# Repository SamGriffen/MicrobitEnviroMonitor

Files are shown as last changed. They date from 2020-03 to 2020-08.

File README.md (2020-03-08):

# MicrobitEnviroMonitor
ESP based webserver for displaying data from weather:bit. This project will allow for the sparkfun weather:bit to send data to an ESP32, which will then display the data on a local webpage. The ESP32 must have a network to connect to, it does not create it's own local access point.
 
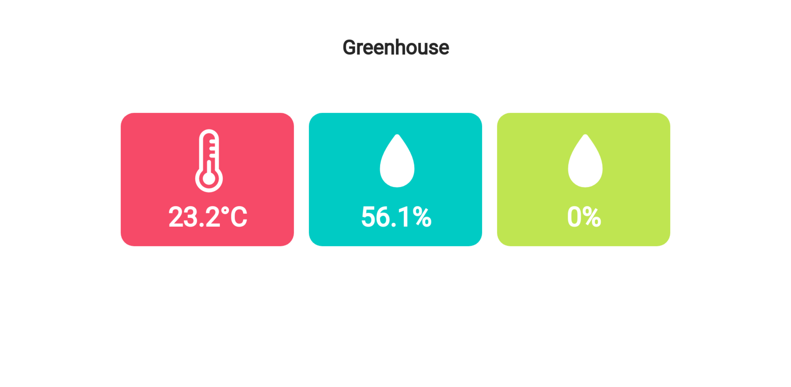
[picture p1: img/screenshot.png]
web interface
 
 
# MicroBit Code
MicroBit code can be downloaded here: https://makecode.microbit.org/_66RTrKJwsf48
The hex file can be found in the `microbit` folder of the repository.
 
 # Setup
 After cloning the repository, the project can be opened in PlatformIO. Web data is loaded into the SPIFFs storage on the ESP32, and the platformio config files are setup to allow for this. To install out of the box you must do the following:
 
 - Edit `ssid` and `password` at the top of the file to contain your WiFi network credentials.
 - Plug in ESP32.
 - From terminal, run `pio run --target uploadfs` in the root directory of the project. This will upload all web files to the ESP.
 - The project can then be uploaded as per usual.
 - Once running, the IP address of the ESP should be logged to the serial monitor (If DEBUG is defined). Navigate to this in a web browser, and the interface should appear.
 
 # Wiring Notes
 The following connections need to be made:
 weather:bit RX --> ESP32 GPIO17
 weather:bit TX --> ESP32 GPIO16
 weather:bit GND --> ESP32 GND

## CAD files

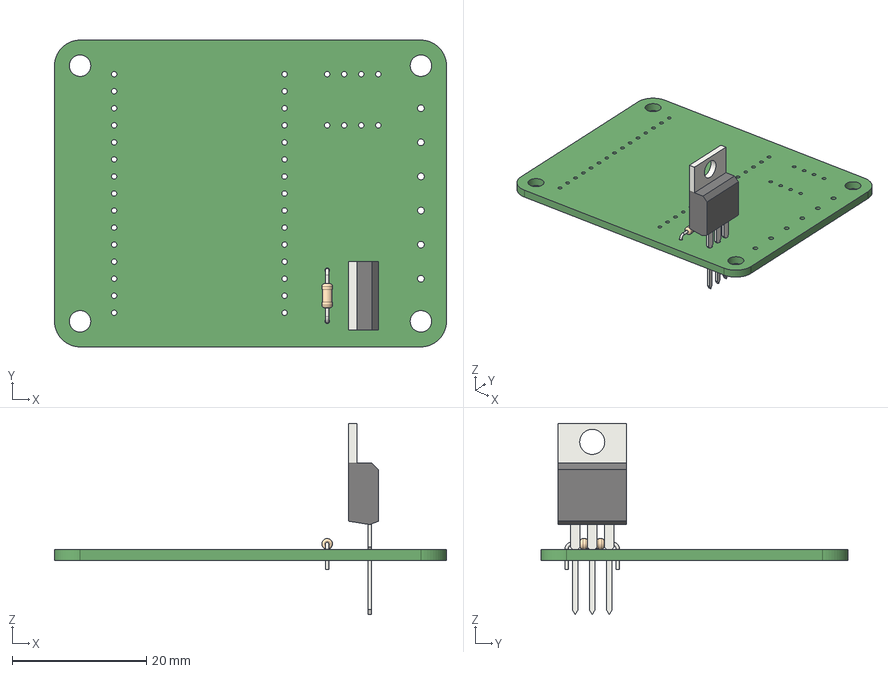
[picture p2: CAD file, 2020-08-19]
KiCAD/microbit-enviromonitor-board/microbit-enviromonitor-board.step
58.4 x 45.7 x 28.5 mm

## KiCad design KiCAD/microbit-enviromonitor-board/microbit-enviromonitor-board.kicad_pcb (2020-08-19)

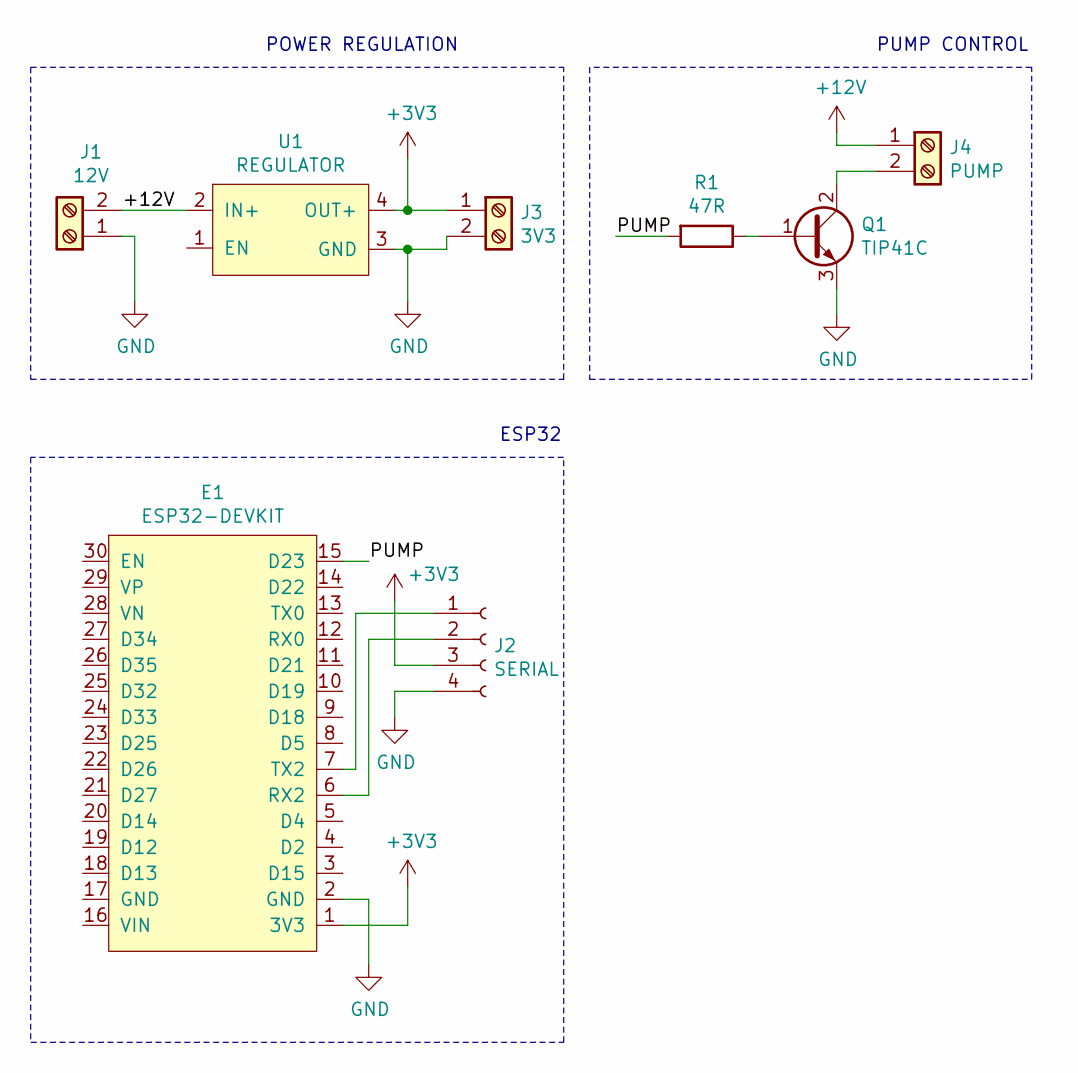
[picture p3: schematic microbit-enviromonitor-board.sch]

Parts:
E1: ESP32-DEVKIT; ESP31-DEVKIT
J1: 12V; screw_terminal
J2: SERIAL; 4x1
J3: 3V3; screw_terminal
J4: PUMP; screw_terminal
Q1: TIP41C; TO-220-3_Horizontal_TabDown
R1: 47R; R_Axial_DIN0204_L3.6mm_D1.6mm_P7.62mm_Horizontal
U1: REGULATOR; buck_converter

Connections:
+3V3: E1.1 (3V3), J2.3, J3.1, U1.4 (OUT+)
+12V: J1.2, J4.1, U1.2 (IN+)
/PUMP: E1.15 (D23), R1.2
GND: E1.2 (GND), J1.1, J2.4, J3.2, Q1.3 (E), U1.3 (GND)
unnamed: E1.6 (RX2), J2.2
unnamed: E1.7 (TX2), J2.1
unnamed: J4.2, Q1.2 (C)
unnamed: Q1.1 (B), R1.1

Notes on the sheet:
POWER REGULATION
PUMP CONTROL
ESP32

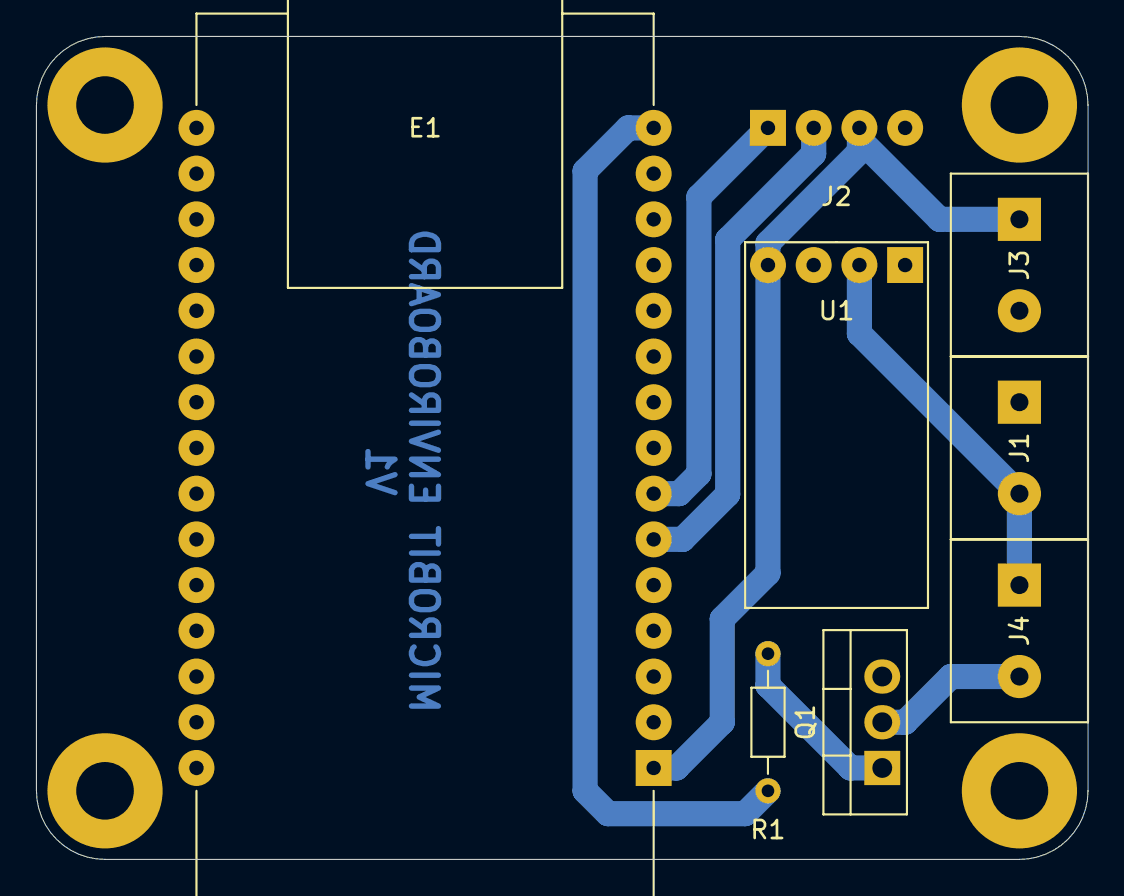
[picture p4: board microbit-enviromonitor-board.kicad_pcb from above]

Board: 2 copper layers, 58.4 x 45.7 mm, 8 parts (0 on the bottom side), 8 nets.

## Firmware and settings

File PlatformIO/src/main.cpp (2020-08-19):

/**
 * Code for Microbit based Environmental Monitoring station.
 * 
 * Data is received via serial, in the following format:
 * [temperature, in... centidegrees? Divide value by 100 to get degrees celsius], [humidity, divide by 1024 to get % relative humidity], [soil moisture. 0-1023, 0 being dry, 1023 being wet], [wind speed in m/s], [wind direction string], [mm of rain]
 * 
 * TODO: Make SOIL_DRY adjustable without reprogramming. This poses a security risk, so will need to be secure and able to detect misuse (Such as leaving the pump on indefinitely)
 * TODO: Handle rain gauge
 */

#include <Arduino.h>
#include <WiFi.h>
#include <ESPAsyncWebServer.h>
#include <SPIFFS.h>

#define DEBUG

// Define the point at which the soil is defined as "dry". Any value below this will activate the pump
// TODO: Make this editable via the frontend interface
#define SOIL_DRY 600

// Define pump output, and pump state flag
#define PUMP_PIN 23
bool pump_on = false; // Pump state. True = on, false = off


#define PUMP_BUTTON 18 // For attaching a pump activate button. When pressed, the pump will activate for roughly a minute.


// Network credentials

// const char* ssid = "BV9800";
// const char* password = "testpassword";

// Struct for storing current reading data
struct Data{
  double temp; // Temperature in degrees celsius
  double humidity; // Relative humidity [%]
  int soil_moist; // Soil moisture. A reading between 0 and 1024. This needs to be manually read and tuned, it doesn't really mean a whole lot
  double wind_speed; // Wind speed in meters per second
  char wind_dir[3];  // Wind direction, string containing "N", "NE", "E", "SE", "S" "SW", "W", or "NW"
  double rain;  // mm of rainfall since last reading was sent
} data;

#ifdef DEBUG
// If there is debugging enabled, declare a function for printing the data read
void printData(Data dat){
  Serial.print("Temperature: ");Serial.println(dat.temp);
  Serial.print("Humidity: ");Serial.println(dat.humidity);
  Serial.print("Soil Moisture: ");Serial.println(dat.soil_moist);
  Serial.print("Wind Speed ");Serial.println(dat.wind_speed);
  Serial.print("Wind Direction: ");Serial.println(dat.wind_dir);
  Serial.print("Last Hour of Rain: ");Serial.println();
}
#endif

char buffer[32]; // Buffer for storing incoming serial data for processing

bool reading = false; // Represents whether serial data is currently being read
int buf_cur = 0; // Current position in buffer

// Methods for handling Serial data
void incoming();
void processBuffer();

/* NETWORK SETUP */

// Create AsyncWebServer object on port 80
AsyncWebServer server(80);

// Method for processing HTML templates
String processor(const String& var);

// Configure the pump button interrupt routine
unsigned long press_length = 60000; // When the button is pressed, leave the pump on for a minute
unsigned long press_time = 0;
bool pressed = false;

void IRAM_ATTR ISR(){
  pump_on = true;
  press_time = millis();
  pressed = true;
}

void setup() {
  pinMode(PUMP_BUTTON, INPUT_PULLUP); // Set the pump input button as a pulup input

  attachInterrupt(PUMP_BUTTON, ISR, FALLING);

  Serial.begin(9600);

  #ifdef DEBUG
  while(!Serial){}
  #endif

  Serial2.begin(9600); // Initialise Serial communication with the microbit

  // Initialise the pump
  pinMode(PUMP_PIN, OUTPUT);
  digitalWrite(PUMP_PIN, pump_on);

  if(!SPIFFS.begin(true)){ // Attempt to initialise SPIFFS
    #ifdef DEBUG
    Serial.println("SPIFFS could not be initialised.");
    #endif
    return;
  }

  // Connect to Wi-Fi
  WiFi.begin(ssid, password);
  while (WiFi.status() != WL_CONNECTED) {
    delay(1000);
    #ifdef DEBUG
    Serial.println("Connecting to WiFi..");
    #endif
  }

  // Print ESP32 Local IP Address
  Serial.println(WiFi.localIP());

  // Configure all the routes on the HTTP server

  // Serve basic webpage
  server.on("/", HTTP_GET, [](AsyncWebServerRequest *request){
    request->send(SPIFFS, "/index.html", String(), false, processor);
  });

  // Serve request for page data
  server.on("/data", HTTP_GET, [](AsyncWebServerRequest *request){
    char buf[256];
    memset(buf, 0, 256);

    // Convert all floats to strings
    char temp[6];
    dtostrf(data.temp, 4,1, temp);

    char humidity[6];
    dtostrf(data.humidity, 3,1, humidity);

    char wind[5];
    dtostrf(data.wind_speed, 4, 2, wind);

    sprintf(buf, "{\"temp\":%s, \"humidity\":%s, \"soil_moist\":%d, \"wind_speed\":%s, \"wind_dir\":\"%s\", \"pump_on\":%d}", temp, humidity, data.soil_moist, wind, data.wind_dir, pump_on);

    request->send(200, "application/json", buf);
  });

  // Serve stylesheet
  server.on("/styles.css", HTTP_GET, [](AsyncWebServerRequest *request){
    request->send(SPIFFS, "/styles.css","text/css");
  });

  // Serve SVG images
  server.on("/drop.svg", HTTP_GET, [](AsyncWebServerRequest *request){
    request->send(SPIFFS, "/drop.svg","image/svg+xml");
  });

  server.on("/temp.svg", HTTP_GET, [](AsyncWebServerRequest *request){
    request->send(SPIFFS, "/temp.svg","image/svg+xml");
  });
  
  server.on("/plant.svg", HTTP_GET, [](AsyncWebServerRequest *request){
    request->send(SPIFFS, "/plant.svg","image/svg+xml");
  });

  server.on("/plant_water.svg", HTTP_GET, [](AsyncWebServerRequest *request){
    request->send(SPIFFS, "/plant_water.svg","image/svg+xml");
  });

  server.on("/wind.svg", HTTP_GET, [](AsyncWebServerRequest *request){
    request->send(SPIFFS,"/wind.svg"
    ,"image/svg+xml");
  });

  // Serve JavaScript file
  server.on("/main.js", HTTP_GET, [](AsyncWebServerRequest *request){
    request->send(SPIFFS, "/main.js","text/javascript");
  });

  server.on("/set_pump", HTTP_POST, [](AsyncWebServerRequest *request){
    pump_on = request->getParam("pump_on", true)->value() == "true";
    Serial.print("Pump: ");Serial.println(pump_on);
    request->send(200, "text/plain", "OK");
  });

  // Admin interface - Crudely password protected by ADMIN_PASS
  server.begin();
}

void loop() {
  if(Serial2.available() > 0){ // Handle incoming Serial
    incoming();
  }

  // If the button timeout has been reached, turn off pump
  if(pressed && (millis() - press_time > press_length)){
    pressed = false;
    pump_on = false;
  }

  digitalWrite(PUMP_PIN, pump_on); // Set the pump output
}

/**
 * Process the HTML template, replacing variables with data from the microbit
 */
String processor(const String& var){
  if(var == "TEMP")return String(data.temp, 1);
  if(var == "HUMIDITY")return String(data.humidity, 1);
  if(var == "SOIL")return String(data.soil_moist, 1);
  if(var == "PUMP")return String(pump_on ? "ON" : "OFF");
  if(var == "WIND_SPEED")return String(data.wind_speed, 1);
  if(var == "WIND_DIR")return String(data.wind_dir);
  return String();
}

/**
 * Process an incoming character on Serial
 */
void incoming(){
  char c = Serial2.read(); // Read the next serial character

    if(reading){
      buffer[buf_cur] = c;
      buf_cur++;
    }

    if(c == '\n' && !reading){
      reading = true; // if serial is not currently being read, start reading it
      #ifdef DEBUG
      Serial.println("Started reading");
      #endif
    }

    else if(c == '\n' && reading){ // end of a data string
      #ifdef DEBUG
      Serial.println("Finished reading. Read:");
      Serial.println(buffer);
      #endif
      buffer[buf_cur] = '\0'; // Null terminate the buffer
      reading = false;
      buf_cur = 0; // reset reading flag, and buffer counter
      processBuffer(); // Process the data that was read
    }
}

/**
 * Process the data buffer, extracting the data into the 'data' struct
 */
void processBuffer(){
  #ifdef DEBUG
  Serial.println("Reading temperature");
  #endif
  char * tok = strtok(buffer, ","); // Get the first token

  if(tok == NULL)return; // Could not read temperature

  data.temp = (double)atoi(tok)/100.0; // Get the temperature

  #ifdef DEBUG
  Serial.println("Reading humidity");
  #endif
  tok = strtok(NULL, ","); // Get the second token

  if(tok == NULL)return; // Could not read humidity

  data.humidity = (double)atoi(tok)/1024.0; // Get the humidity

  #ifdef DEBUG
  Serial.println("Reading soil moisture");
  #endif
  tok = strtok(NULL, ","); // Get the third token

  if(tok == NULL)return; // Could not read soil moisture

  data.soil_moist = atoi(tok); // Read soil moisture content

  #ifdef DEBUG
  Serial.println("Reading wind speed");
  #endif
  tok = strtok(NULL, ","); // Get the fourth token

  if(tok == NULL)return; // Could not read wind speed

  data.wind_speed = atoi(tok); // Read wind speed

  #ifdef DEBUG
  Serial.println("Reading wind direction");
  #endif
  tok = strtok(NULL, ","); // Get the fifth token

  if(tok == NULL)return; // Could not read  wind direction

  strcpy(data.wind_dir, tok); // Read wind direction

  #ifdef DEBUG
  Serial.println("Reading rainfall");
  #endif
  tok = strtok(NULL, ","); // Get the sixth token

  if(tok == NULL)return; // Could not read wind speed

  data.rain = atoi(tok); // Read rainfall

  #ifdef DEBUG
  printData(data);
  #endif
}

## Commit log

2020-03-04 Increased soil moisture print accurracy
2020-03-08 CSS Tweaks
    Improved CSS, will now allow for soil moisture and pump status to be shown. Also made a unique soil moisture icon. Next step is to get these populating with actual controller data.
2020-03-09 Added pump state data
2020-03-16 Modified pump control
2020-07-14 Began work on PCB
    [microbit-enviromonitor-board.kicad_pcb, microbit-enviromonitor-board.sch]
2020-07-17 Updated serial port
    [microbit-enviromonitor-board.kicad_pcb, microbit-enviromonitor-board.sch, microbit-enviromonitor-board.step]
2020-07-17 Added exports
    [microbit-enviromonitor-board-B_Cu.gbr, microbit-enviromonitor-board-Edge_Cuts.gbr, microbit-enviromonitor-board-job.gbrjob]
2020-07-19 Board changes
    [microbit-enviromonitor-board.kicad_pcb, microbit-enviromonitor-board.sch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]
2020-08-19 Added pump switch
    [microbit-enviromonitor-board.kicad_pcb, microbit-enviromonitor-board.sch, microbit-enviromonitor-board.step]
